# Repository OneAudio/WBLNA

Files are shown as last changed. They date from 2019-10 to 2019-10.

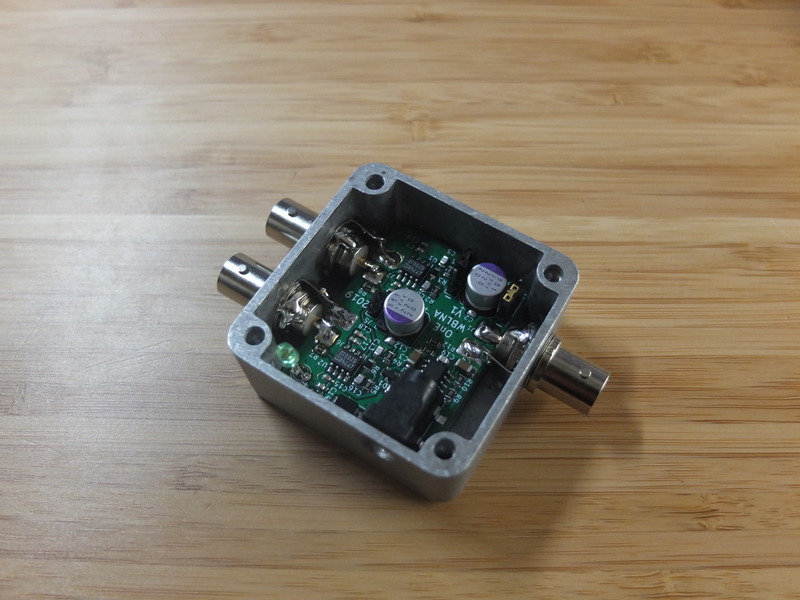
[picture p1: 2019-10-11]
Pictures/WBLNA_02.jpg

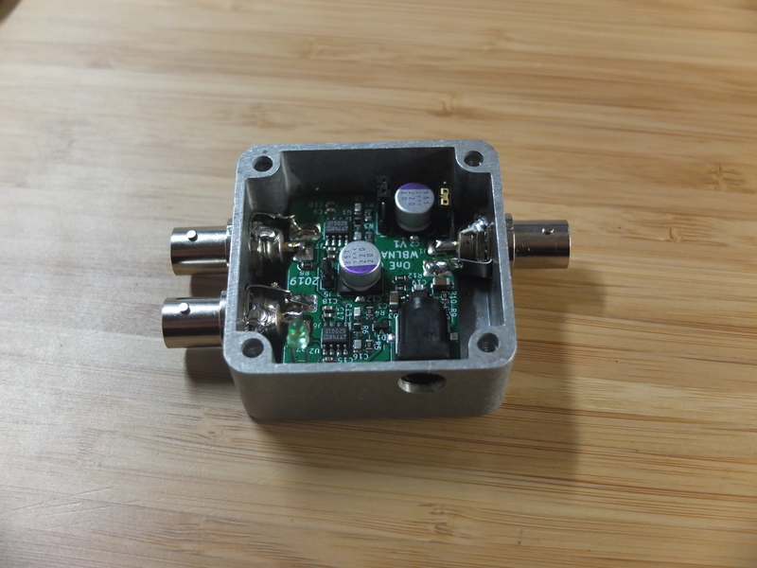
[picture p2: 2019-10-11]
Pictures/WBLNA_05.jpg

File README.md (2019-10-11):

# WBLNA
Wide Bandwidth low noise amplifier 20Hz-20MHz 20/40dB
-----------------------------------------------------

The WBLNA is a low noise high bandwidth amplifier board.
It can be use to many purpose as noise measurement.

## Specs are :
- 20Hz to 20MHz -3dB bandwidth
- +20dB and +40dB gain individual outputs
- 50 Ohms input/output impedance
- AC or DC coupled input (support +/-20V in AC coupled mode).
- Single 12V@50mA DC input jack
- Low overall cost (~30€ of parts + PCB).

This project  is open source and has been designed using Kicad 5.0.2
The Githu repos include all design files like :
- LTspice simulation files and results
- Schematics
- Bill of materials with Mouser order code
- Picture of prototype
- Pulse mesurements
- Mechanical drawing
- And more...

Frex

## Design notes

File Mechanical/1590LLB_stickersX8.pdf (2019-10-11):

Vin Z=50

Ω
100mVpp max

OUT1: Zo=50

Ω
G= +20dB (x10)

OUT2 : Zo=50

Ω
G= +40dB(x100)

## OnE Audio Project - WBLNA

Wide Bandwidth Low-Noise Amplifier en= 12µVrms B-3dB= 20Hz...20MHz

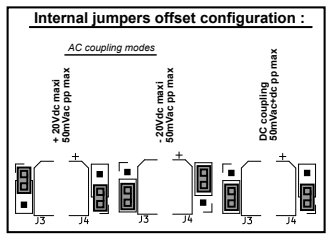
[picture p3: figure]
AC coupling modes

DC INPUT 12Vmax@50mA | ON | Internal jumpers offset configuration : + 20Vdc maxi 50mVac pp max | - 20Vdc maxi 50mVac pp max | DC coupling 50mVac+dc pp max

Vin Z=50

Ω 100mVpp max

OUT1: Zo=50

Ω
G= +20dB (x10)

OUT2 : Zo=50

Ω
G= +40dB(x100)

## OnE Audio Project - WBLNA

Wide Bandwidth Low-Noise Amplifier en= 12µVrms B-3dB= 20Hz...20MHz

DC INPUT

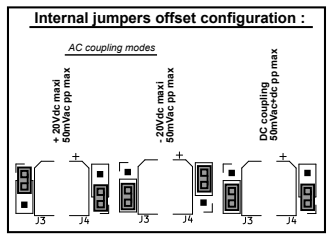
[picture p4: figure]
AC coupling modes

12Vmax@50mA | ON | Internal jumpers offset configuration : + 20Vdc maxi 50mVac pp max | - 20Vdc maxi 50mVac pp max | DC coupling 50mVac+dc pp max

Vin Z=50

Ω
100mVpp max

OUT1: Zo=50

Ω
G= +20dB (x10)

OUT2 : Zo=50

Ω
G= +40dB(x100)

## OnE Audio Project - WBLNA

Wide Bandwidth Low-Noise Amplifier en= 12µVrms B-3dB= 20Hz...20MHz

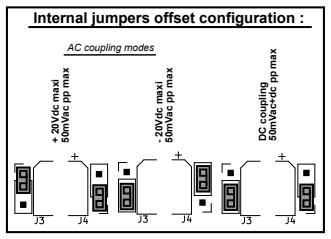
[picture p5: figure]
AC coupling modes

DC INPUT 12Vmax@50mA | ON | Internal jumpers offset configuration : + 20Vdc maxi 50mVac pp max | - 20Vdc maxi 50mVac pp max | DC coupling 50mVac+dc pp max

Vin Z=50

Ω 100mVpp max

OUT1: Zo=50

Ω
G= +20dB (x10)

OUT2 : Zo=50

Ω
G= +40dB(x100)

## OnE Audio Project - WBLNA

Wide Bandwidth Low-Noise Amplifier en= 12µVrms B-3dB= 20Hz...20MHz

DC INPUT

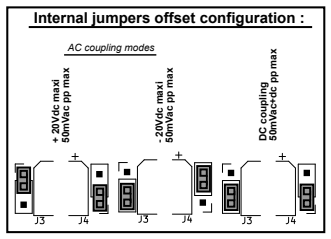
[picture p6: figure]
AC coupling modes

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

Vin Z=50

Ω
100mVpp max

OUT1: Zo=50

Ω G= +20dB (x10)

OUT2 : Zo=50

Ω
G= +40dB(x100)

## OnE Audio Project - WBLNA

Wide Bandwidth Low-Noise Amplifier en= 12µVrms B-3dB= 20Hz...20MHz

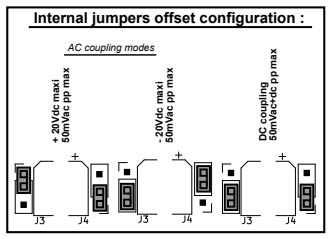
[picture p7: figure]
AC coupling modes

DC INPUT 12Vmax@50mA | ON | Internal jumpers offset configuration : + 20Vdc maxi 50mVac pp max | - 20Vdc maxi 50mVac pp max | DC coupling 50mVac+dc pp max

Vin Z=50

Ω
100mVpp max

OUT1: Zo=50

Ω G= +20dB (x10)

OUT2 : Zo=50

Ω G= +40dB(x100)

## OnE Audio Project - WBLNA

Wide Bandwidth Low-Noise Amplifier en= 12µVrms B-3dB= 20Hz...20MHz

DC INPUT

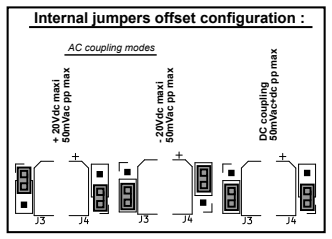
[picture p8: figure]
AC coupling modes

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

Vin Z=50

Ω
100mVpp max

OUT1: Zo=50

Ω
G= +20dB (x10)

OUT2 : Zo=50

Ω
G= +40dB(x100)

## OnE Audio Project - WBLNA

Wide Bandwidth Low-Noise Amplifier en= 12µVrms B-3dB= 20Hz...20MHz

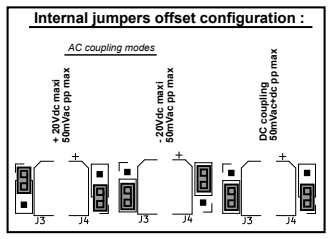
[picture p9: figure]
AC coupling modes

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

Vin Z=50

Ω 100mVpp max

OUT1: Zo=50

Ω
G= +20dB (x10)

OUT2 : Zo=50

Ω
G= +40dB(x100)

## OnE Audio Project - WBLNA

Wide Bandwidth Low-Noise Amplifier en= 12µVrms B-3dB= 20Hz...20MHz

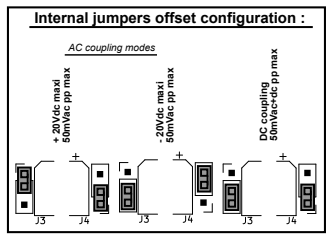
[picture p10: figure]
AC coupling modes

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

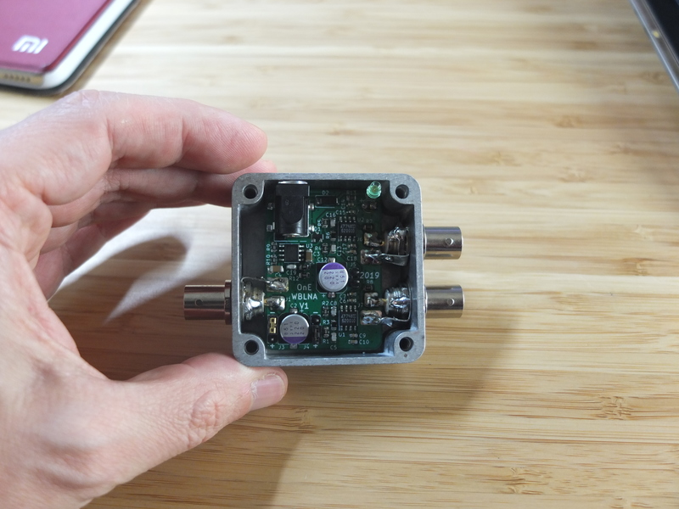
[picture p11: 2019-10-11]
Pictures/WBLNA_03.jpg

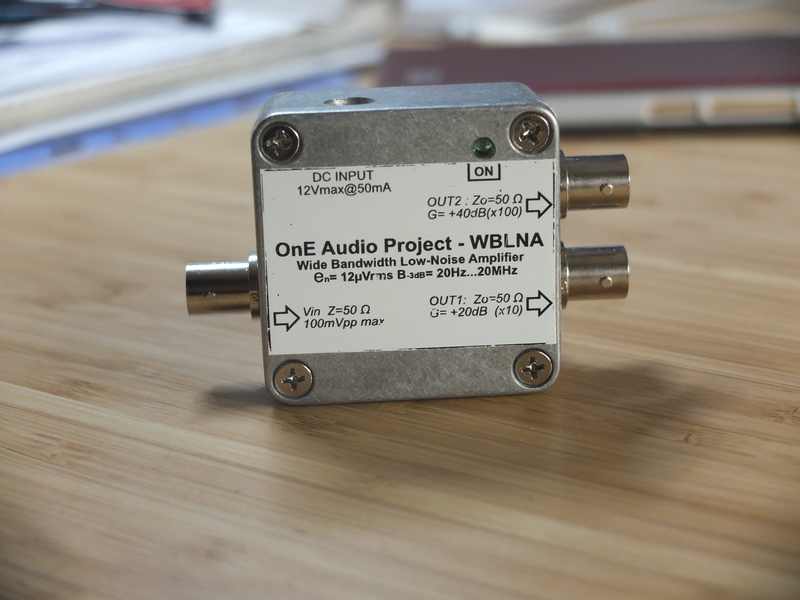
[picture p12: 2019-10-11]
Pictures/WBLNA_07.jpg

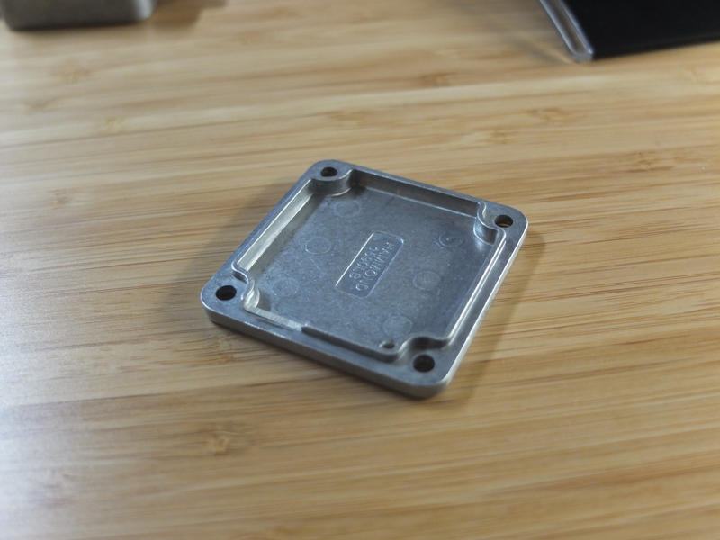
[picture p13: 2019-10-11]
Pictures/WBLNA_01.jpg

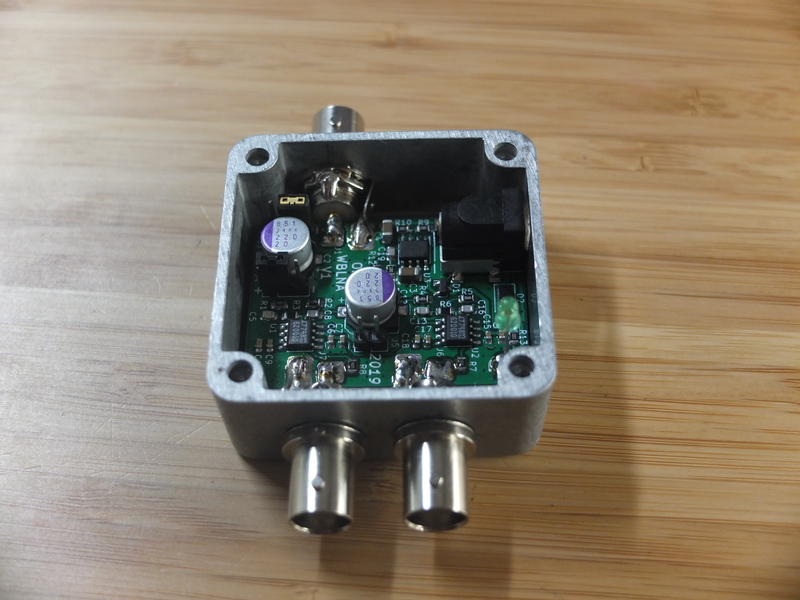
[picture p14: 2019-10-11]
Pictures/WBLNA_04.jpg

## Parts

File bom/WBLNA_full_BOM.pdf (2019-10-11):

WLNAv1_BOM

Source: | _WBLNA\Kicad\_WBLNA.sch
Date: | 20/09/2019 08:41:46
Tool: | Eeschema (5.0.2)-1
Component Count: | 47
Ref | Qnty | Value | Cmp name | Footprint | Description | Distributor Order code | Unit price
BOX1, | 1 | Case_1590LLB_Hammond Case_1590LLB_HammondWBLNA:1590LLB | Hammond aluminium enclosure 1590LLB | Mouser | 546-1590LLB | 6,150 €
C1, | 1 | 100nF/25V X7R | C_Small | Capacitor_SMD:C_0805_2012Metric | Unpolarized capacitor, small symbol | Mouser | 710-885012206071 | 0,033 €
C2, C12, | 2 | 220uF/20V OSCON | CP_Small | Capacitor_SMD:CP_Elec_8x6.9 | Polarized capacitor, small symbol | Mouser | 667-20SVPK220M | 1,480 €
C4, C3, | 2 | 22uF/16V X5R | C_Small | Capacitor_SMD:C_0805_2012Metric | Unpolarized capacitor, small symbol | Mouser | 81-GRM219R61C226ME1K | 0,441 €
C5, C13, | 2 | 270pF/COG | C_Small | Capacitor_SMD:C_0805_2012Metric | Unpolarized capacitor, small symbol | Mouser | 77-VJ0805A271FXACBC | 0,144 €
C8, C16, | 2 | 10pF/COG | C_Small | Capacitor_SMD:C_0805_2012Metric | Unpolarized capacitor, small symbol | Mouser | 77-VJ0805A100FXACBC | 0,126 €
| 5 | 100nF/25V X7R | C_Small | Capacitor_SMD:C_0603_1608Metric | Unpolarized capacitor, small symbol | Mouser | 710-885012206071 | 0,033 €
| 4 | 10nF/25V X7R | C_Small | Capacitor_SMD:C_0603_1608Metric | Unpolarized capacitor, small symbol | Mouser | 710-885012206065 | 0,040 €
C19, | 1 | 1nF/50V COG 2% | C_Small | Capacitor_SMD:C_0805_2012Metric | Unpolarized capacitor, small symbol | Mouser | 77-VJ0805A102GXACBC | 0,189 €
D1, | 1 | BAT54S | BAT54S | Package_TO_SOT_SMD:SOT-23 | schottky barrier diode | Mouser | 863-BAT54SLT1G | 0,126 €
D2, | 1 | P4SMA12A | P4SMA12A | Diode_SMD:D_SMA | Surface Mount TRANSZORBÂ®Transient Voltage Suppressors | Mouser | 625-P4SMA12A-E3 | 0,324 €
D3, | 1 | MBR0540 | MBR0540 | Diode_SMD:D_SOD-123 | 40V 0.5A Schottky Power Rectifier Diode, SOD-123 | Mouser | 863-MBR0540T1G | 0,271 €
D4, | 1 | Led 3mm green | LED_ALT | LED_THT:LED_D3.0mm_Clear | Light emitting diode, filled shape | Mouser | 710-151031VS06000 | 0,140 €
J1, J6, J7, | 3 | BNC | Conn_Coaxial | WBLNA:BNC_edge_solderSMD | coaxial connector (BNC, SMA, SMB, SMC, Cinch/RCA, ...) | Mouser | 571-5-1634523-1 | 1,310 €
J2, | 1 | Jack-DC | Jack-DC | WBLNA:BarrelJackSMD_Wurth_694108106102 | DC Barrel Jack | Mouser | 710-694106106102 | 1,540 €
J4, J3, | 2 | Jumper_NC_Dual | Jumper_NC_Dual | Connector_PinHeader_2.54mm:PinHeader_1x03_P2.54mm_VerticalDual jumper, normally closed | Mouser | 855-M20-9730345 | 0,162 €
J5, | 1 | Jumper_NC_Small | Jumper_NC_Small | Connector_PinHeader_2.54mm:PinHeader_1x02_P2.54mm_VerticalJumper, normally closed, small symbol | Mouser | 855-M20-9730245 | 0,144 €
R2, R5, | 2 | 499 | R_Small | Resistor_SMD:R_0805_2012Metric | Resistor, small symbol | Mouser | 71-CRCW0805499RFKEA | 0,090 €
R3, R6, | 2 | 39.2 | R_Small | Resistor_SMD:R_0805_2012Metric | Resistor, small symbol | Mouser | 71-CRCW0805-39.2-E3 | 0,090 €
R8, R1, R7, R4, | 4 | 49.9 | R_Small | Resistor_SMD:R_0805_2012Metric | Resistor, small symbol | Mouser | 71-CRCW080549R9FKEAC | 0,090 €
R9, R10, R13, | 3 | 10k | R_Small | Resistor_SMD:R_0805_2012Metric | Resistor, small symbol | Mouser | 71-CRCW080510K0FKEA | 0,090 €
R11, | 1 | 10 | R_Small | Resistor_SMD:R_0805_2012Metric | Resistor, small symbol | Mouser | 71-CRCW080510R0FKEA | 0,090 €
R12, | 1 | 4.99k | R_Small | Resistor_SMD:R_0805_2012Metric | Resistor, small symbol | Mouser | 71-CRCW08054K99FKEA | 0,090 €
U1, U2, | 2 | LT6200CS8-10#PBF | LT6200-10 | Package_SO:SOIC-8_3.9x4.9mm_P1.27mm | | Mouser | 584-LT6200CS8-10#PBF | 3,280 €
U3, | 1 | AD8510ARZ | AD8510ARZ | Package_SO:SOIC-8_3.9x4.9mm_P1.27mm | Precision, Very Low Noise, Low Input Bias Current, Wide Bandwidth JFET Operational Amplifiers | Mouser | 584-AD8510ARZ | 2,520 €
TOTAL | 28,128 €

C9, C7, C17, C15,
C11,
C10, C6, C18,
C14,

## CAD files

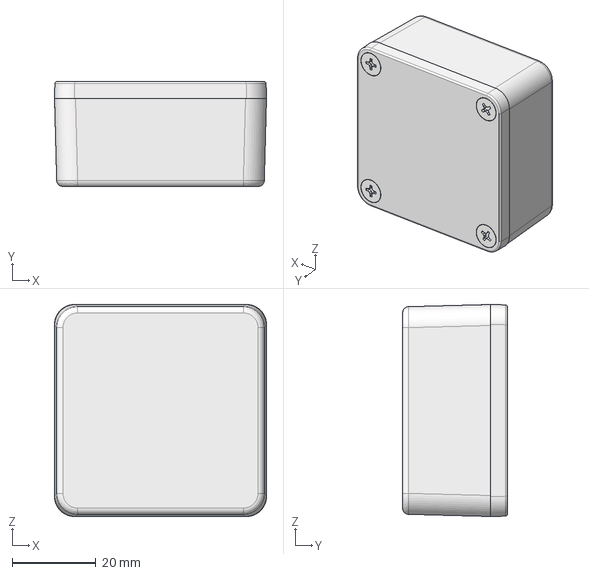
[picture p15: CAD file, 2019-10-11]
3D/1590LLB.stp
50.5 x 25.0 x 50.5 mm

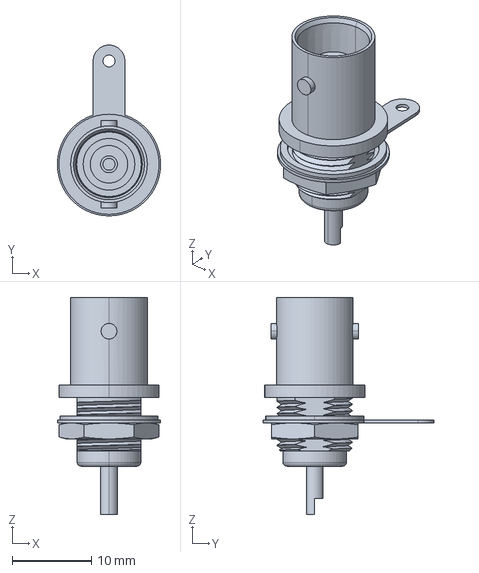
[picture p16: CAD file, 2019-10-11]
3D/c-5-1634523-1-b-3d.stp
13.0 x 21.5 x 27.3 mm

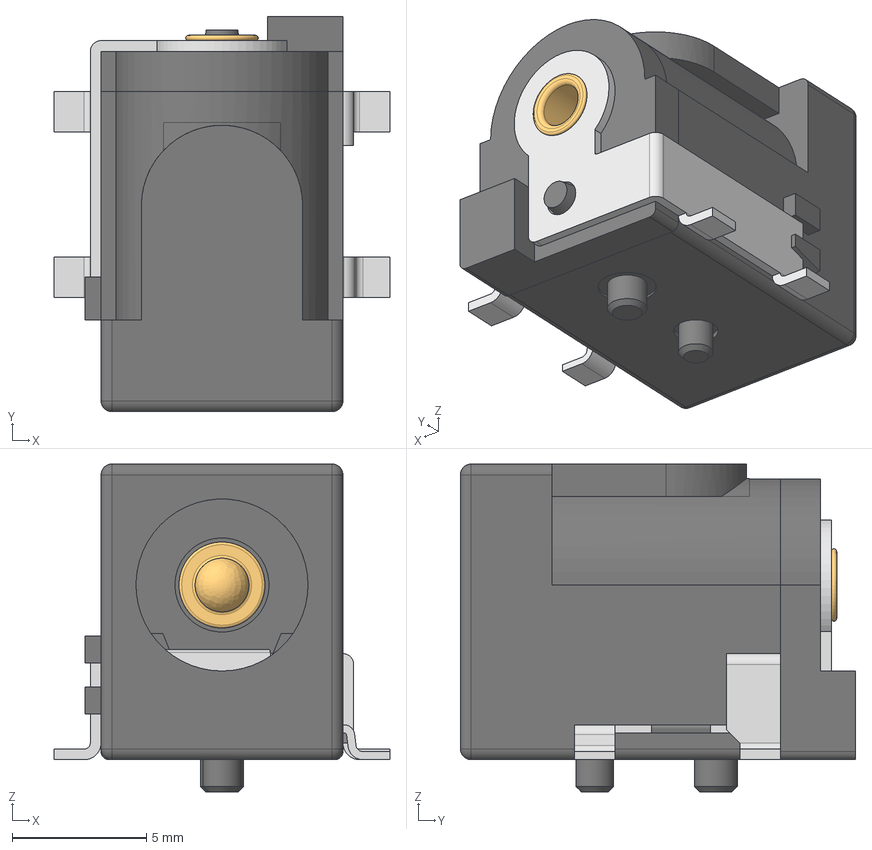
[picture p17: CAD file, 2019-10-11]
3D/694106106102 (rev1).stp
12.5 x 14.7 x 12.2 mm
6941xx106102
6941xx106102_Capot
694106301002_PinContact
6941xx106102_PIN
6941xx106102_PINBIS
6941xx106102_PINLAME

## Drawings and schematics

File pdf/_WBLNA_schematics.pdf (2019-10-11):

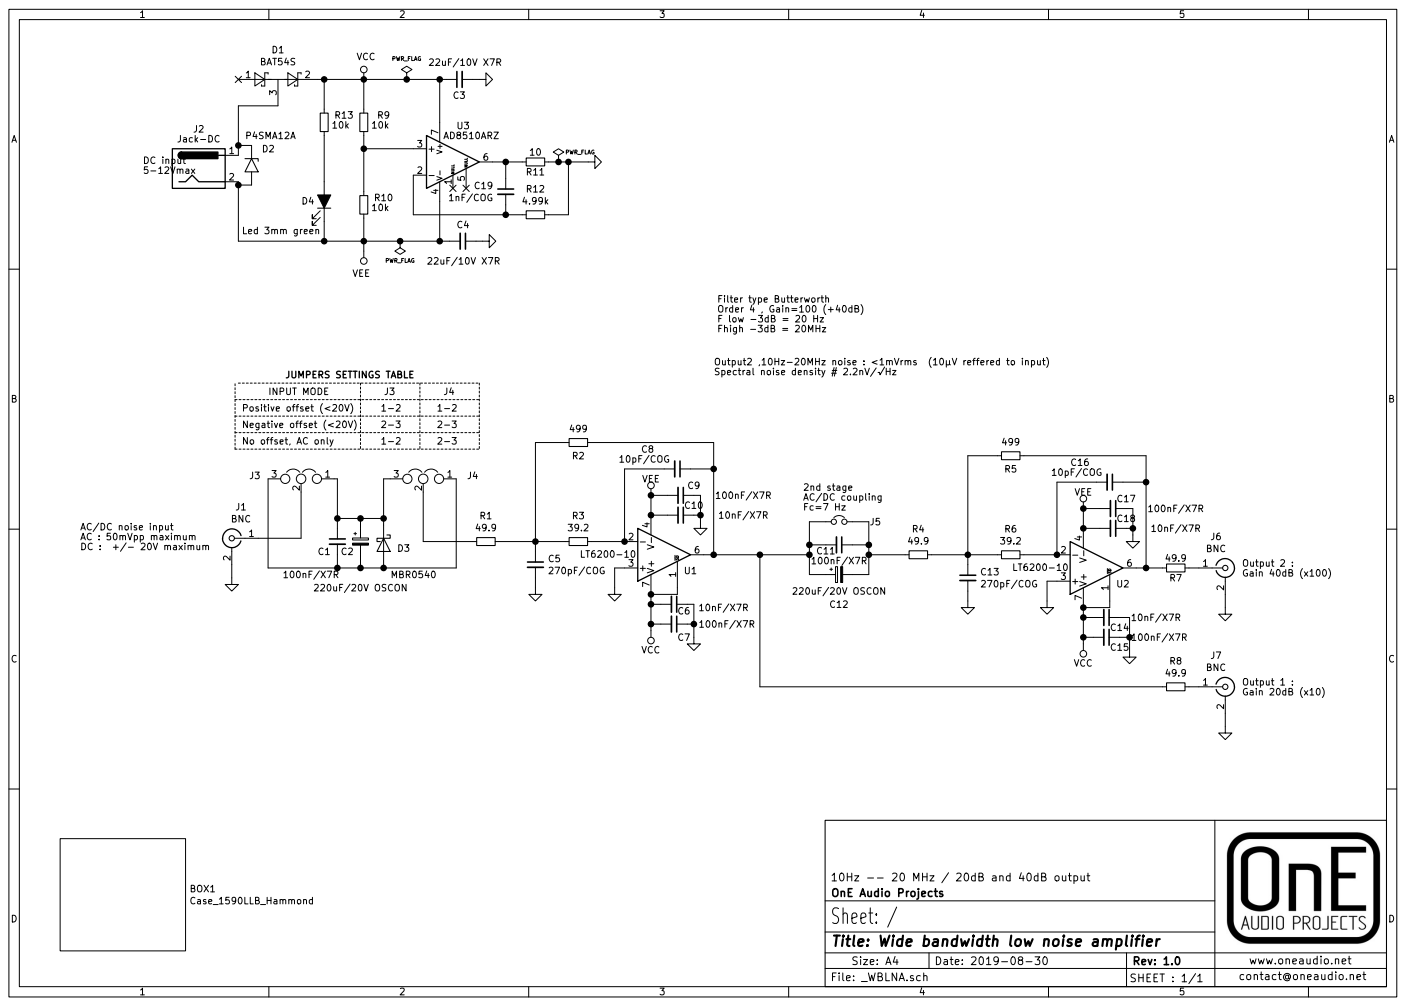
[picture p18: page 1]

AC/DC coupling Fc=7 Hz Filter type Butterworth
Order 4 , Gain=100 (+40dB) F low -3dB = 20 Hz Fhigh -3dB = 20MHz

Output2 ,10Hz-20MHz noise : <1mVrms (10µV reffered to input)
Spectral noise density # 2.2nV/Hz

INPUT MODE | J3 | J4 Positive offset (<20V)
No offset, AC only Negative offset (<20V) | 1-2 2-3 | 1-2 2-3

AC : 50mVpp maximum DC : +/- 20V maximum

OnE Audio Projects
Sheet: /

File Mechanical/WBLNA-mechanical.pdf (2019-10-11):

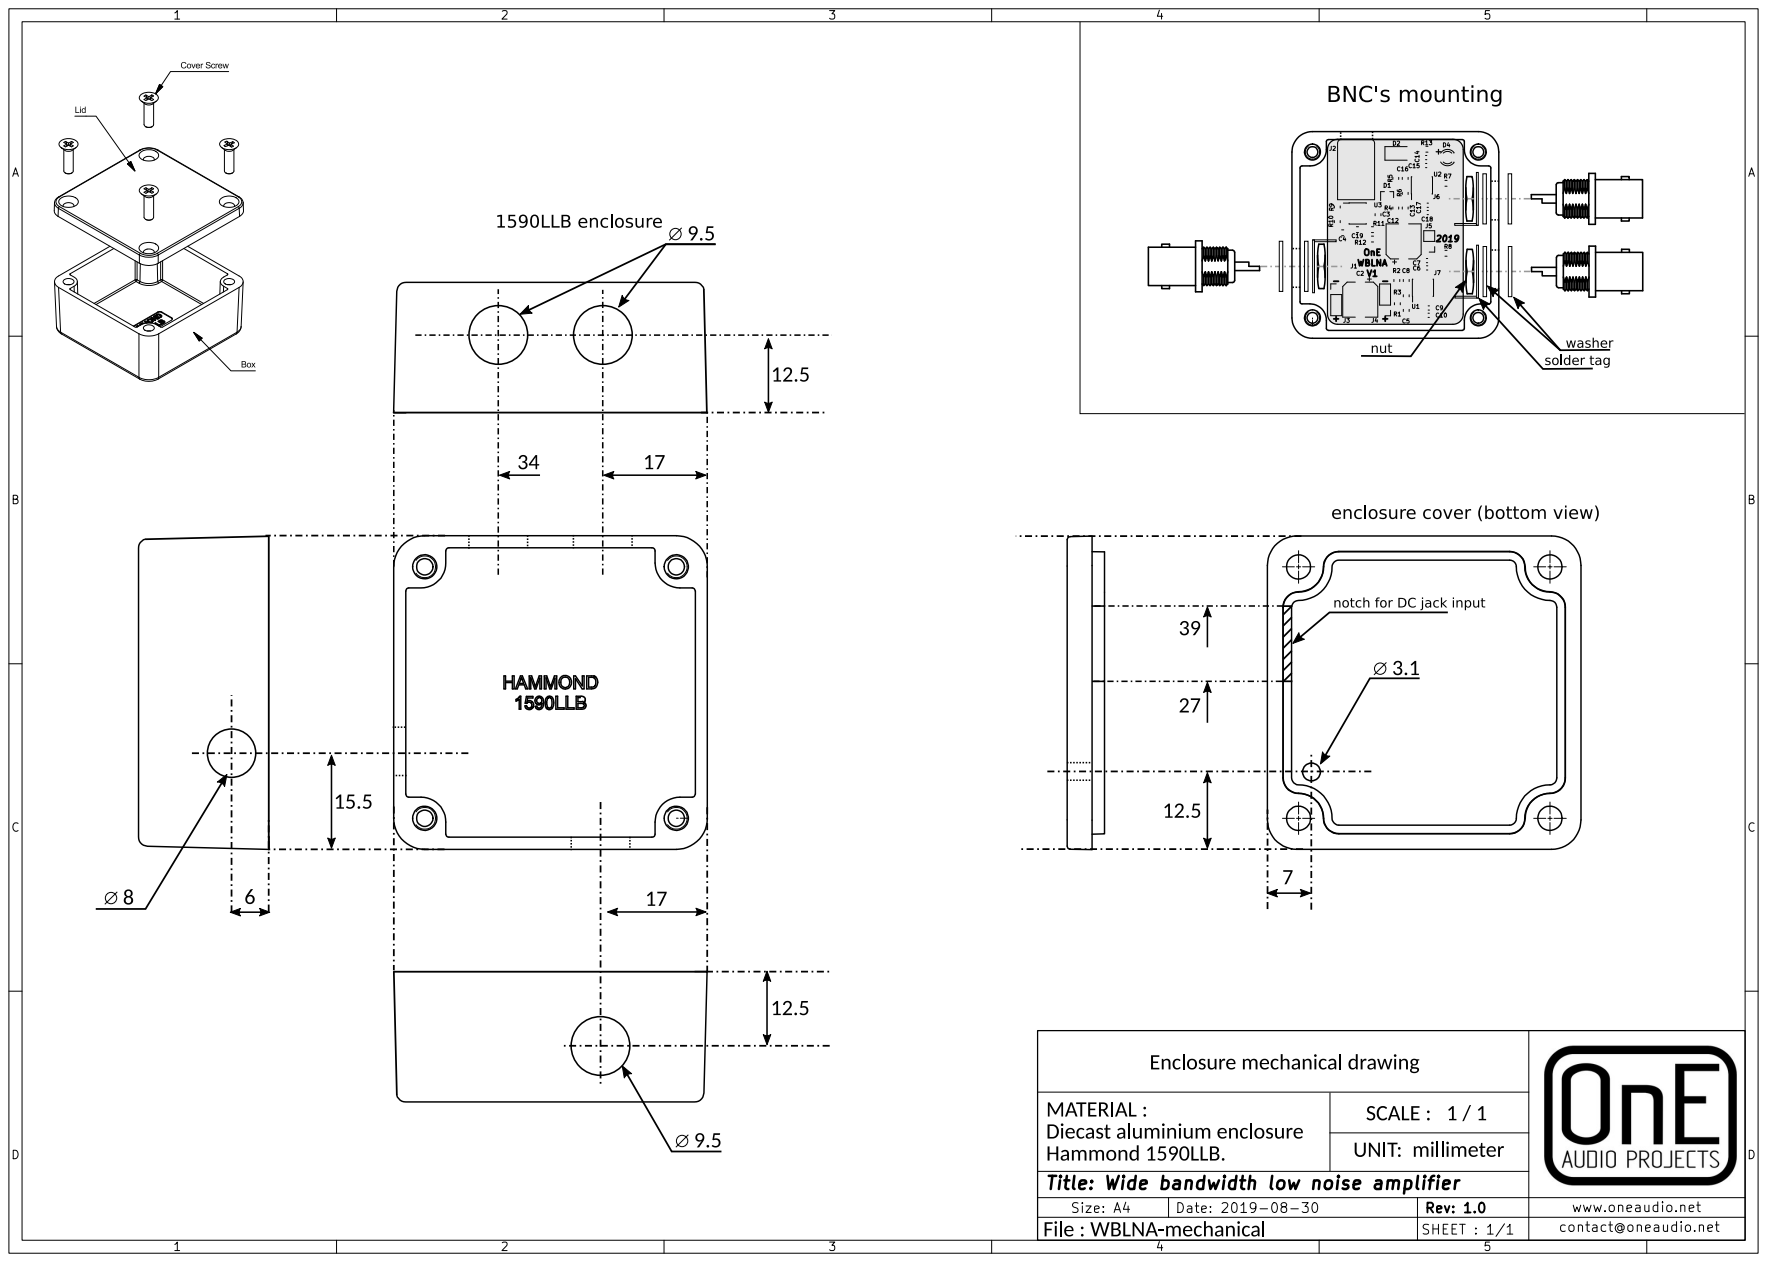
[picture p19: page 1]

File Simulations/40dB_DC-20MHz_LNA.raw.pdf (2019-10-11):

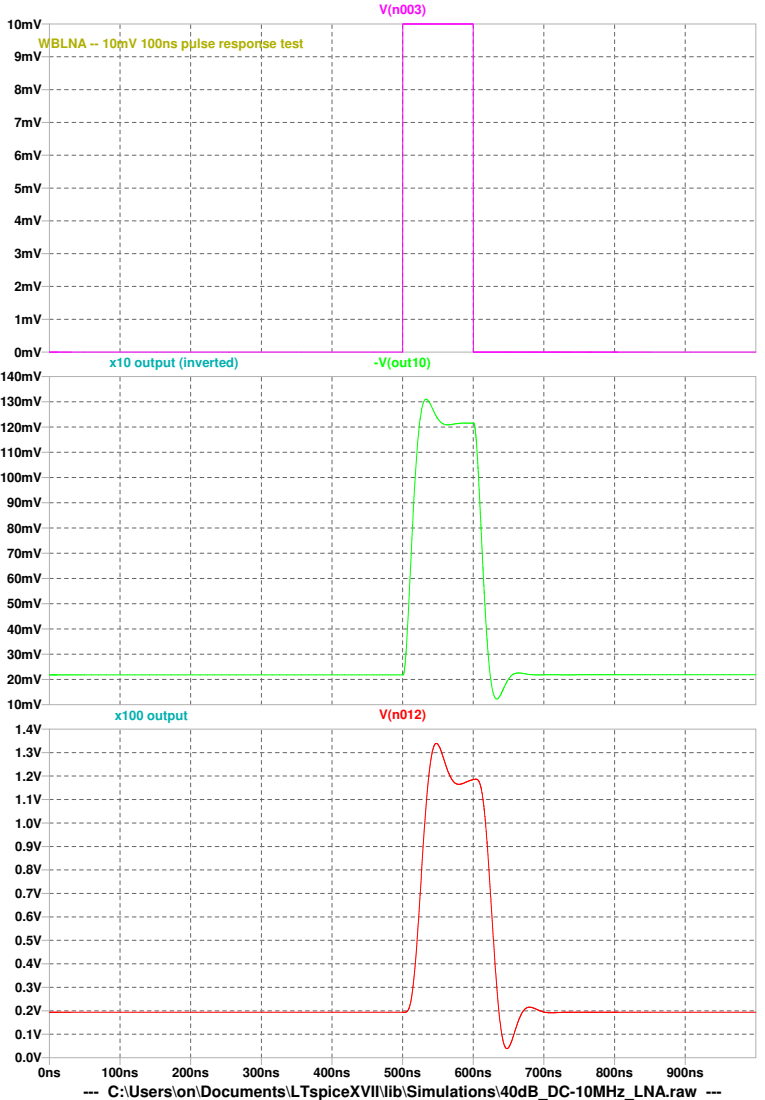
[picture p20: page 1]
-V(out10); x100 output; x10 output (inverted); WBLNA -- 10mV 100ns pulse response test

--- C:\Users\on\Documents\LTspiceXVII\lib\Simulations\40dB_DC-10MHz_LNA.raw ---

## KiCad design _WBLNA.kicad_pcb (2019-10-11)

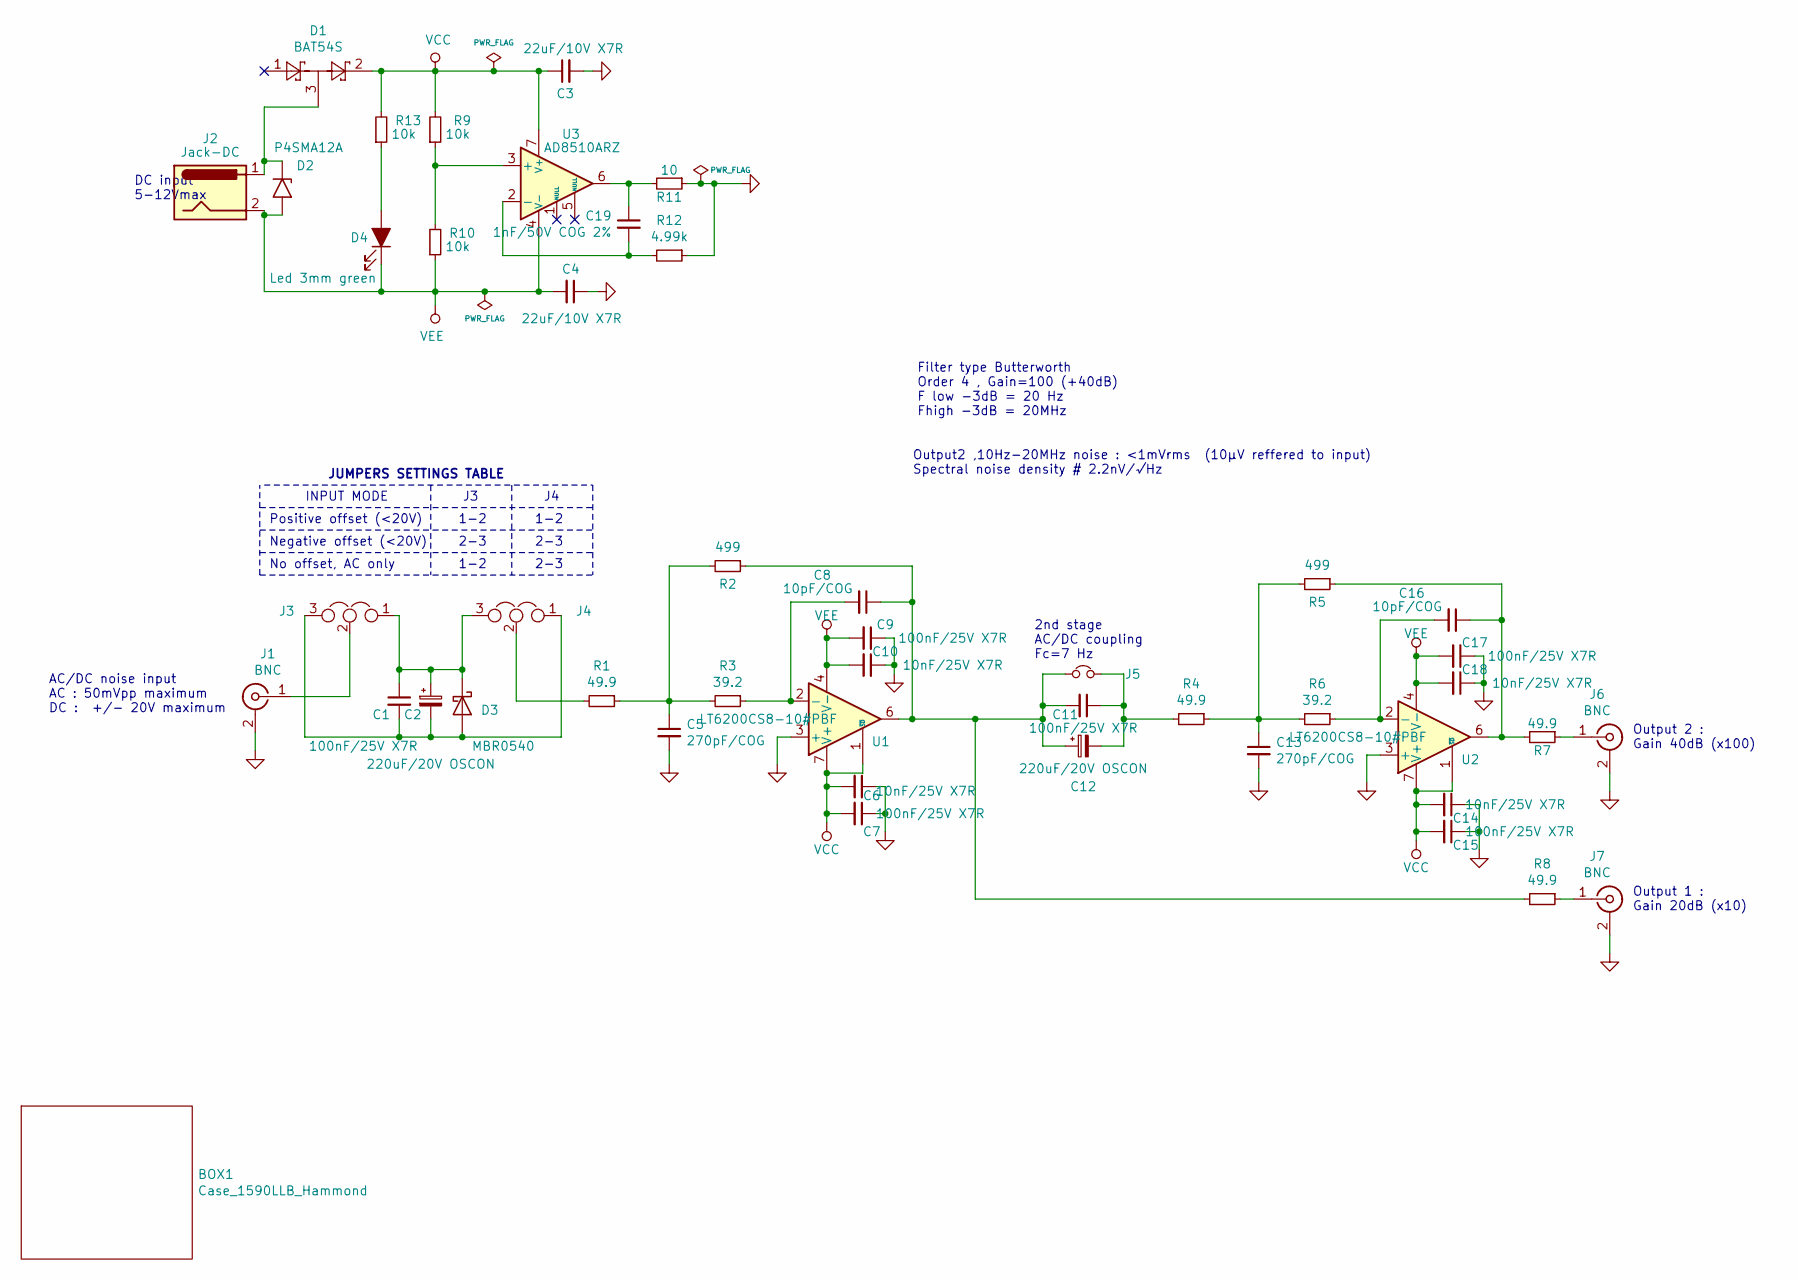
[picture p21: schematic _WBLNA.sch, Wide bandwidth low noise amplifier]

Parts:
BOX1: Case_1590LLB_Hammond; 1590LLB
C1: 100nF/25V X7R; C_0805_2012Metric
C2, C12: 220uF/20V OSCON; CP_Elec_8x6.9
C3, C4: 22uF/10V X7R; C_0805_2012Metric
C5, C13: 270pF/COG; C_0805_2012Metric
C6, C10, C14, C18: 10nF/25V X7R; C_0603_1608Metric
C7, C9, C11, C15, C17: 100nF/25V X7R; C_0603_1608Metric
C8, C16: 10pF/COG; C_0805_2012Metric
C19: 1nF/50V COG 2%; C_0805_2012Metric
D1: BAT54S; SOT-23
D2: P4SMA12A; D_SMA
D3: MBR0540; D_SOD-123
D4: Led 3mm green; LED_D3.0mm_Clear
J1, J6, J7: BNC; BNC_edge_solderSMD
J2: Jack-DC; BarrelJackSMD_Wurth_694108106102
J3, J4: Jumper_NC_Dual; PinHeader_1x03_P2.54mm_Vertical
J5: Jumper_NC_Small; PinHeader_1x02_P2.54mm_Vertical
R1, R4, R7, R8: 49.9; R_0805_2012Metric
R2, R5: 499; R_0805_2012Metric
R3, R6: 39.2; R_0805_2012Metric
R9, R10, R13: 10k; R_0805_2012Metric
R11: 10; R_0805_2012Metric
R12: 4.99k; R_0805_2012Metric
U1, U2: LT6200CS8-10#PBF; SOIC-8_3.9x4.9mm_P1.27mm
U3: AD8510ARZ; SOIC-8_3.9x4.9mm_P1.27mm

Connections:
GND: C3.2, C4.1, C5.2, C6.1, C7.1, C9.1, C10.1, C13.2, C14.1, C15.1, C17.1, C18.1, J1.2 (Ext), J6.2 (Ext), J7.2 (Ext), R11.1, R12.1, U1.3 (+), U2.3 (+)
unnamed: C1.1, C2.1, D3.1 (K), J3.1, J4.3
unnamed: C1.2, C2.2, D3.2 (A), J3.3, J4.1
unnamed: C5.1, R1.1, R2.2, R3.2
unnamed: C8.2, R3.1, U1.2 (-)
unnamed: C11.1, C12.2, J5.2, R4.2
unnamed: C8.1, C11.2, C12.1, J5.1, R2.1, R8.2, U1.6
unnamed: C13.1, R4.1, R5.2, R6.2
unnamed: C16.1, R5.1, R7.2, U2.6
unnamed: C16.2, R6.1, U2.2 (-)
unnamed: C19.1, R11.2, U3.6
unnamed: C19.2, R12.2, U3.2 (-)
unnamed: D1.3, D2.1 (K1), J2.1
unnamed: D4.2 (A), R13.1
unnamed: J1.1 (In), J3.2
unnamed: J4.2, R1.2
unnamed: J6.1 (In), R7.1
unnamed: J7.1 (In), R8.1
unnamed: R9.1, R10.2, U3.3 (+)
VCC: C3.1, C6.2, C7.2, C14.2, C15.2, D1.2, R9.2, R13.2, U1.1 (~SD), U1.7 (V+), U2.1 (~SD), U2.7 (V+), U3.7 (V+)
VEE: C4.2, C9.2, C10.2, C17.2, C18.2, D2.2 (A1), D4.1 (K), J2.2, R10.1, U1.4 (V-), U2.4 (V-), U3.4 (V-)

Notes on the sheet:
Output 1 : Gain 20dB (x10)
Output 2 : Gain 40dB (x100)
JUMPERS SETTINGS TABLE
INPUT MODE
Positive offset (<20V)
Negative offset (<20V)
No offset, AC only
1-2
2-3
AC/DC noise input AC : 50mVpp maximum DC : +/- 20V maximum
2nd stage AC/DC coupling Fc=7 Hz
Filter type Butterworth Order 4 , Gain=100 (+40dB) F low -3dB = 20 Hz Fhigh -3dB = 20MHz
Output2 ,10Hz-20MHz noise : <1mVrms (10µV reffered to input) Spectral noise density # 2.2nV/√Hz
DC input 5-12Vmax

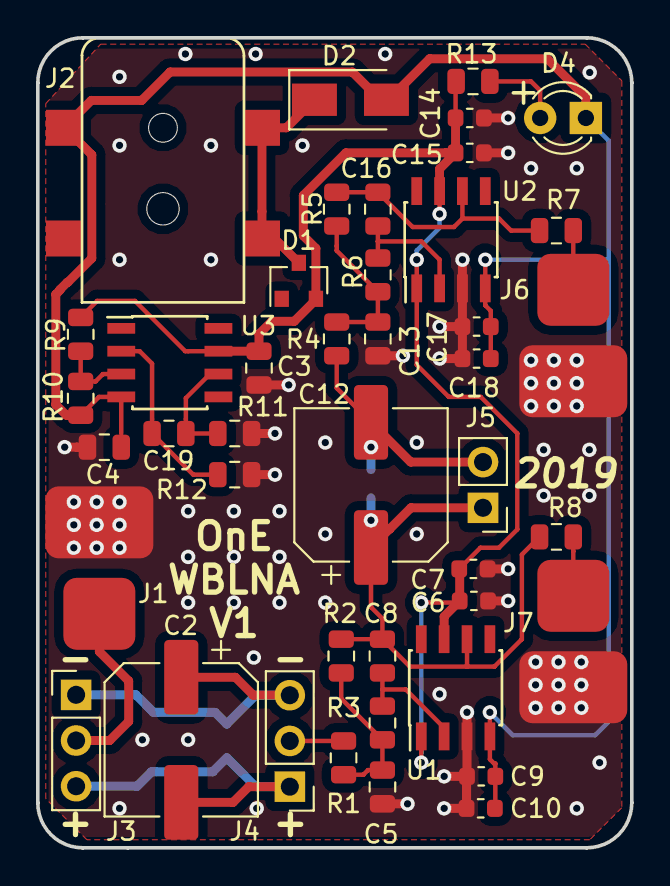
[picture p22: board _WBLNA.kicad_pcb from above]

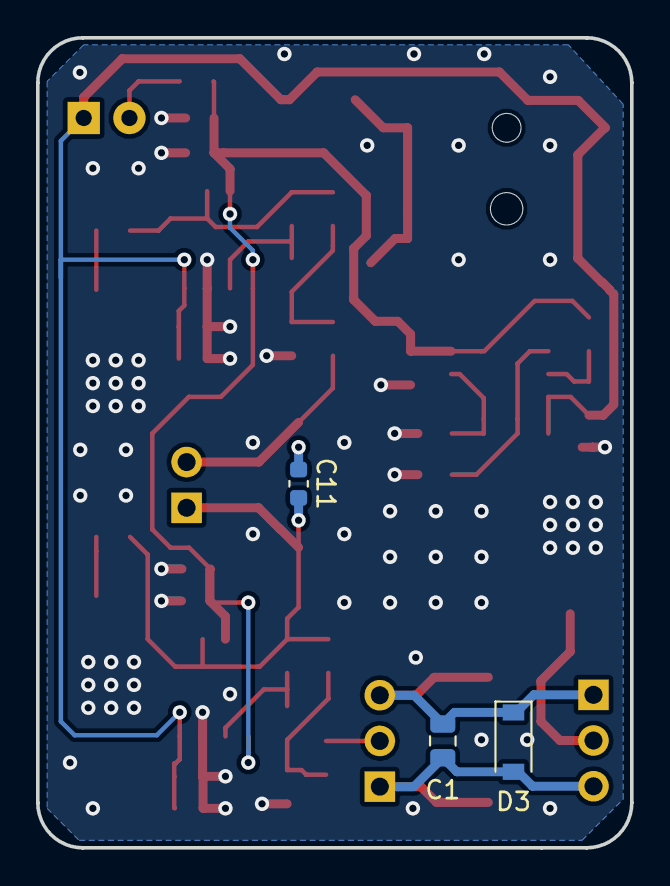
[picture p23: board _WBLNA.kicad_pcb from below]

Board: 2 copper layers, 33.0 x 45.0 mm, 47 parts (3 on the bottom side), 21 nets.
